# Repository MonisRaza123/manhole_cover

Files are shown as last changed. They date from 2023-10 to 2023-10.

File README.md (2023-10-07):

# MCMS (Manhole Cover Monitoring System)

## Problem Statement
Theft of manhole covers is a severe problem faced by our nation that has been left unaddressed for a long time.The repercussions of this thievery not only amount to material losses but also lead to loss of lives. This project proposes a solution to this problem by building a manhole cover monitoring system. Given that a sensor placed inside the manhole will not have reliable connection to the internet, we can directly send the sensor details using internet. This system will give the real-time status of the covers using a LoRa-based gateway to send the data to a cloud server keeping the authorities informed.

## Introduction and Motivation
Theft of manhole covers leads to accidents and deaths. At
first, this might seem like a very unlikely problem, but in
2004 Calcutta witnessed the theft of more than 10000
manhole covers over a period of two months. Thieves
steal these covers to sell them as scrap iron, the profit
made out of these acts is not much but the loss incurred
by society is much greater.
This type of theft is performed at locations experiencing
less traffic and spots which are not monitored with CCTV
cameras. These uncovered holes pose serious danger to
vehicles, especially two-wheelers which end in fatal crashes.
The pedestrians might be able to spot a big hole in daylight
but at night in darkness the chances of any mishappening
increase manifold.
Thus it becomes imperative to come up with a solution
to curb these acts of petty thievery leading to unfortunate
fatalities.

## Proposed Solution
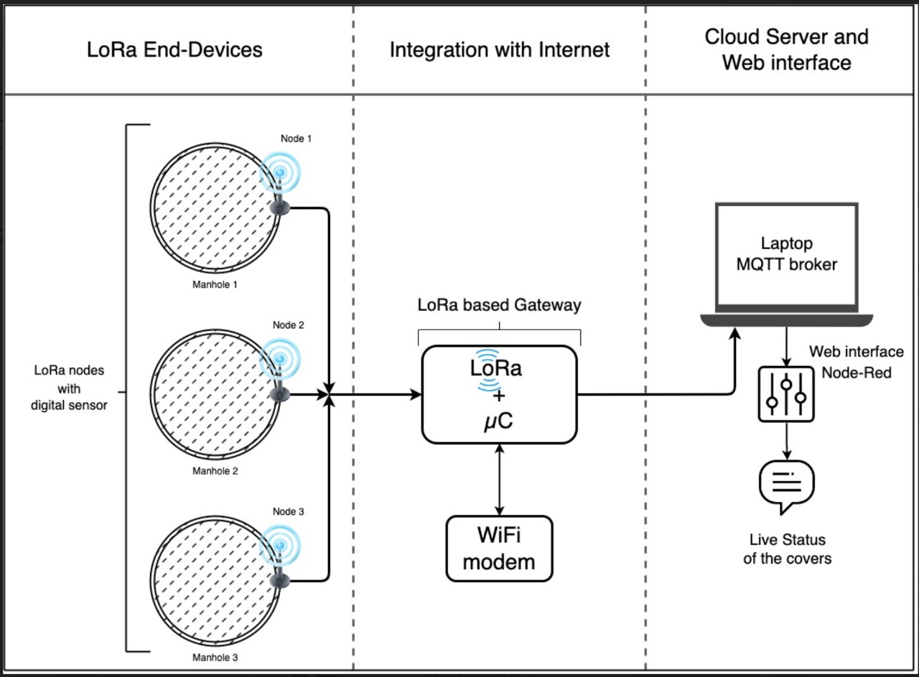
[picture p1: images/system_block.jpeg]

The suggested model is represented in three sections:

1. **LoRa end-devices:** The end devices are composed of sensors capable of
monitoring the status of the cover on the manhole.
The microcontroller reading this sensor is integrated
with a LoRa transmitter.
1. **Integrating internet connectivity:** Signals from the nodes of a given region would be
received by a common LoRa-based gateway connected
to an internet access point.
1. **Cloud server and web interface:** Using the connectivity provided by the gateway, the
data is uploaded to a cloud-based server and displayed
on a web interface or sent to the municipal authorities.

## Block Diagram Representation
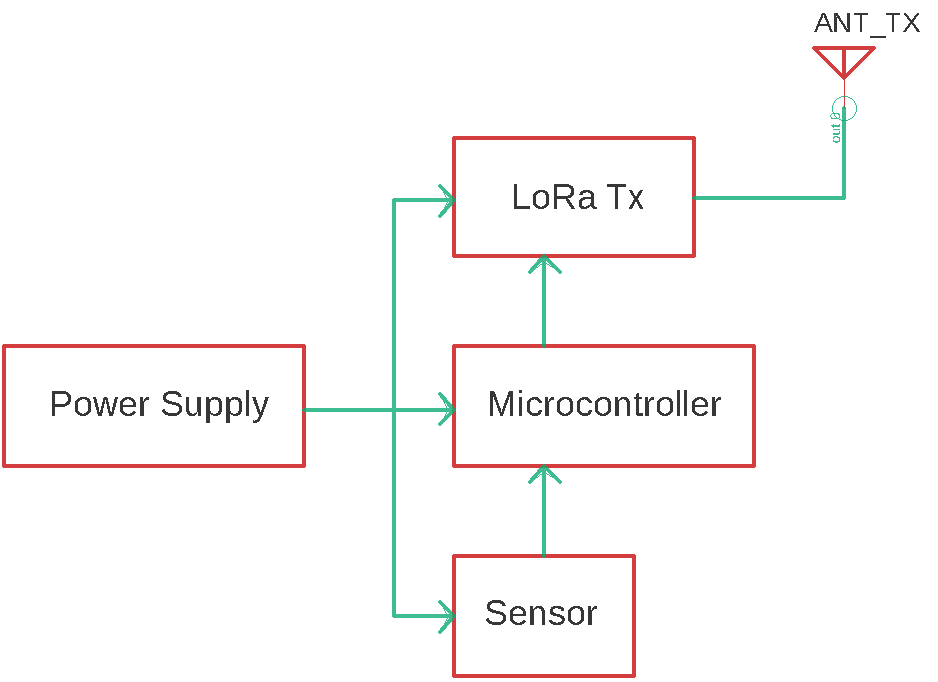
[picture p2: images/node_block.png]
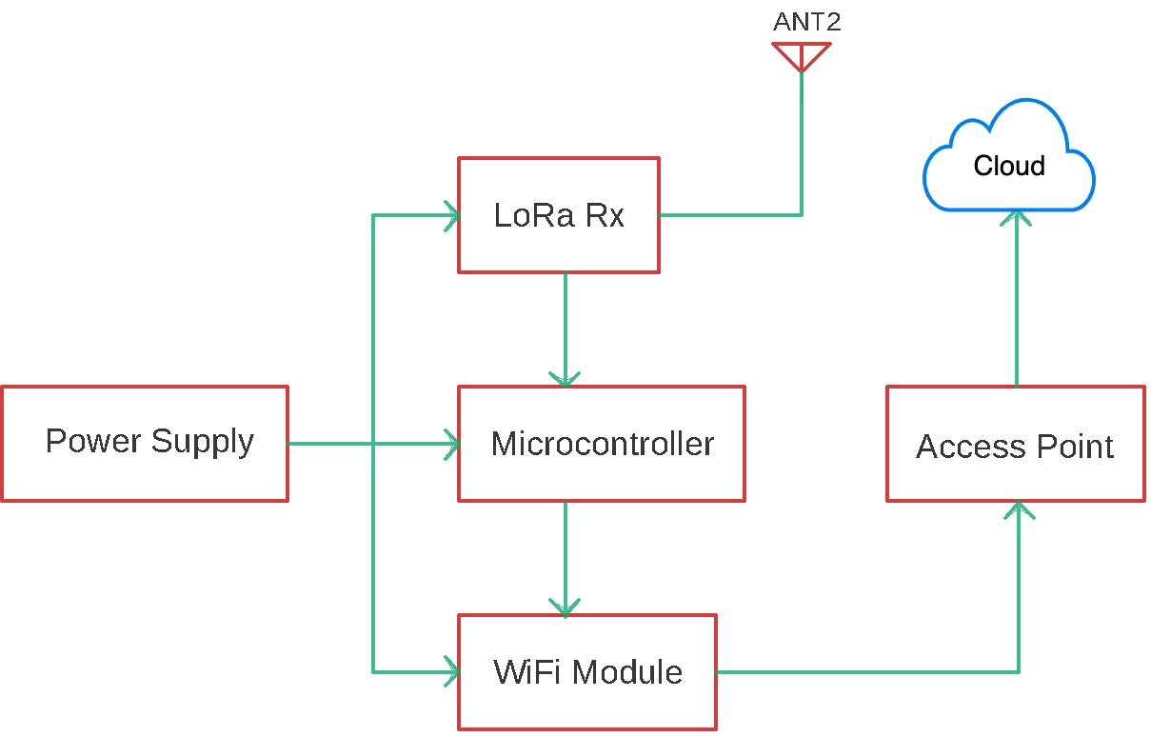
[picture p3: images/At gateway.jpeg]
|||
|:--:|:--:|
|*Manhole(End Node)*|*Gateway*|

## Six Box Model
The following is the list of requirements for the proposed solution as per the 'Six box Model' for embedded systems:
- Input sensor to detect the status of the manhole cover.
- Wireless technology for transferring sensor information.
- Cloud server acting as the host and storage for the required data.
- Microcontroller to process and control the node and gateway.
- Power supply for the node and gateway.
- Output devices to access the monitoring of the manhole covers.

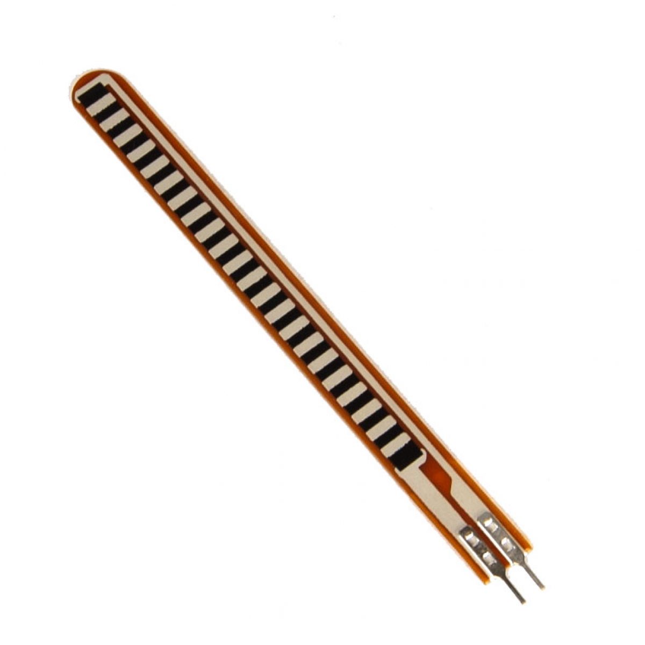
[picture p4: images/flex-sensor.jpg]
|1. INPUT- Flex sensor is used as the input sensor to detect the status of the manhole cover by bending at different angles. The resistance of the sensor changes with change in bending angle thereby facilitating the detection of the presence/absence of the cover.||
|:--|--:|
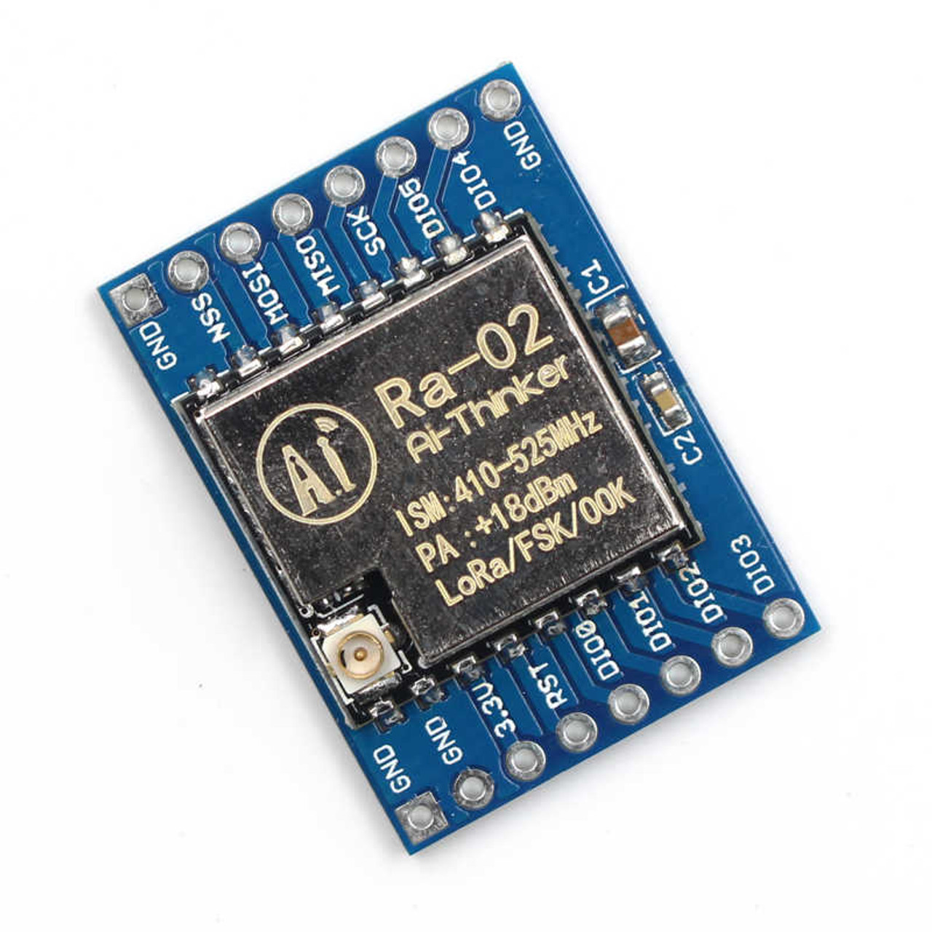
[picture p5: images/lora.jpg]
|2. COMMUNICAITON- LoRa communication is used as the preferred communication technology between the sensor node and the gateway because: i) Internet connectivity is not a viable option for the application. ii) LoRa is ideal for low bandwidth battery operated systems as it consumes minimal power ||
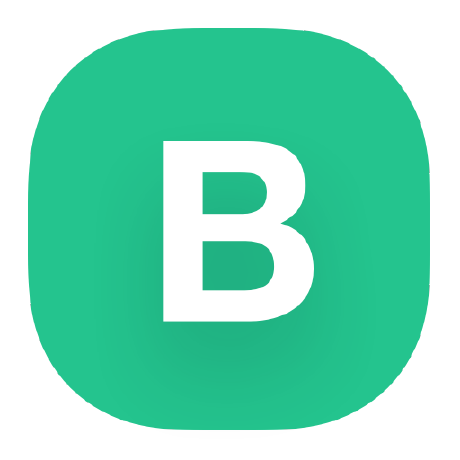
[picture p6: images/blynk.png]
|3. HOST & STORAGE- Blynk IOT serves as the cloud service provider. It stores and hosts the cover status of multiple node devices centrally which can then be fetched remotely from anyplace and anytime.||
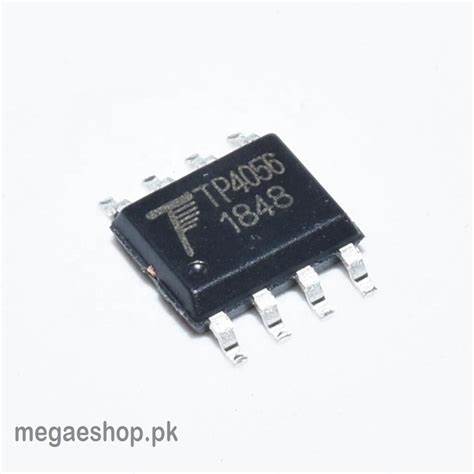
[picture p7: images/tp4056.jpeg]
|4. POWER SUPPLY- The end nodes are powered by a battery and as such need to be charged periodically.The TP4056 is a complete constant-current/constant-voltage linear charger for single-cell lithium-ion batteries. Its SOP package and low external component count make the TP4056 ideally suited for portable applications. The gateway device is powered by a 5V DC adapter||

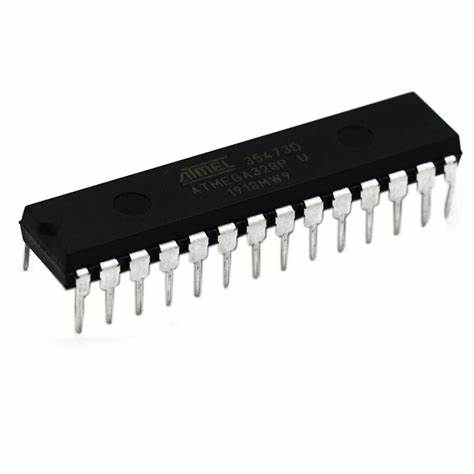
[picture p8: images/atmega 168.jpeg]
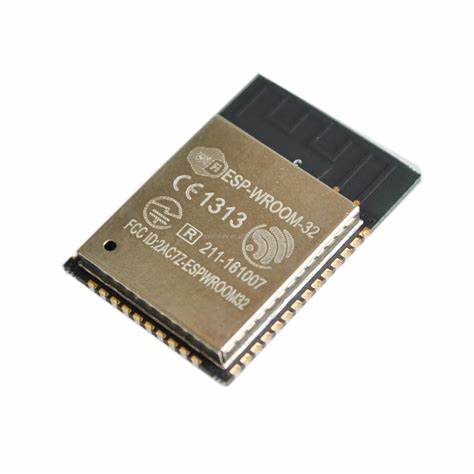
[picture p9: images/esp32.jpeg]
|<span style="font-weight:normal">5. MICROCONTROLLERS- ATMEGA168 is the microcontroller of choice for the end node as it consumes very less power and has just the right amount of features to cater to the needs of the end device. ESP32 is used as the microcontroller at the gateway as it requires internet connectivity serving as the internet access point for multiple end nodes. The communication between the end-nodes and gateway is done using Lora transceivers as stated earlier</span>|||
|:--|--|--:|

## Circuit Design

### Schematics
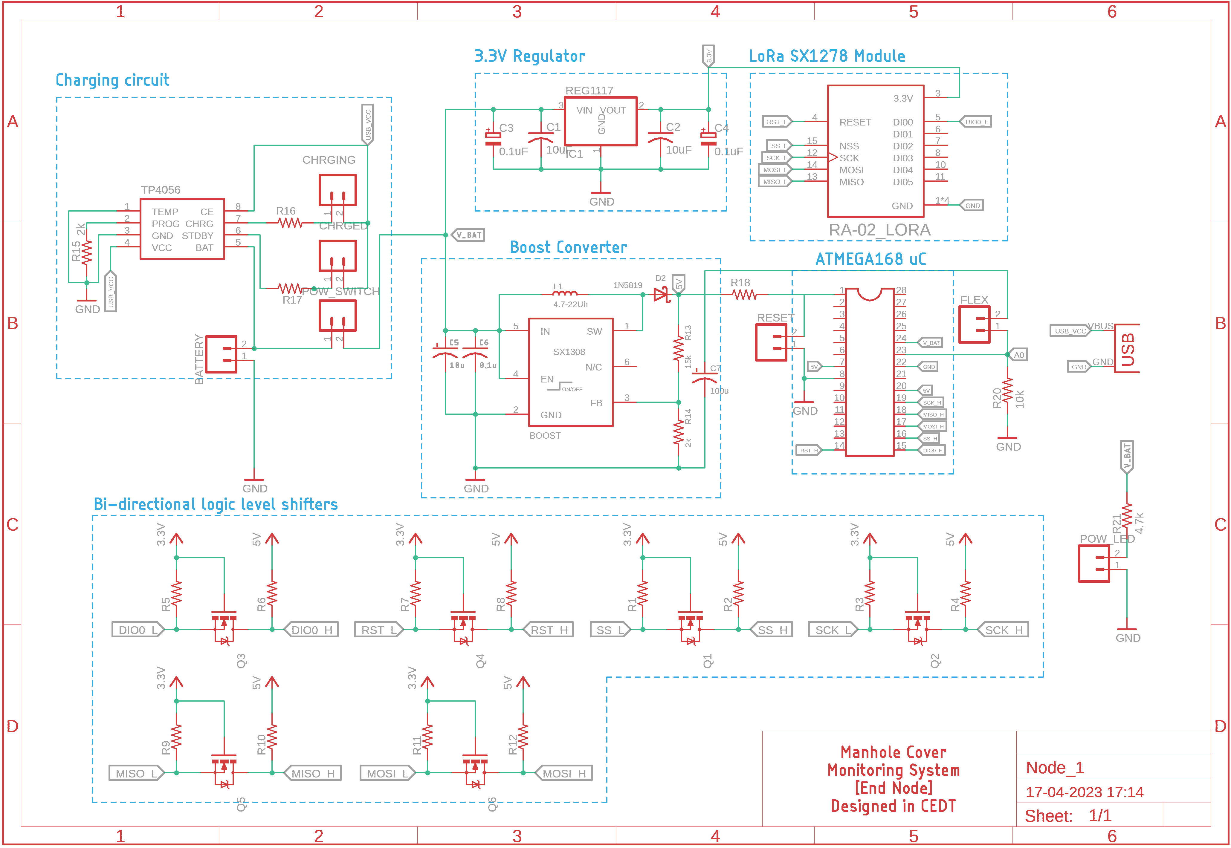
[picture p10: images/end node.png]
||
|:--:|
|*Schematic for End Node*|

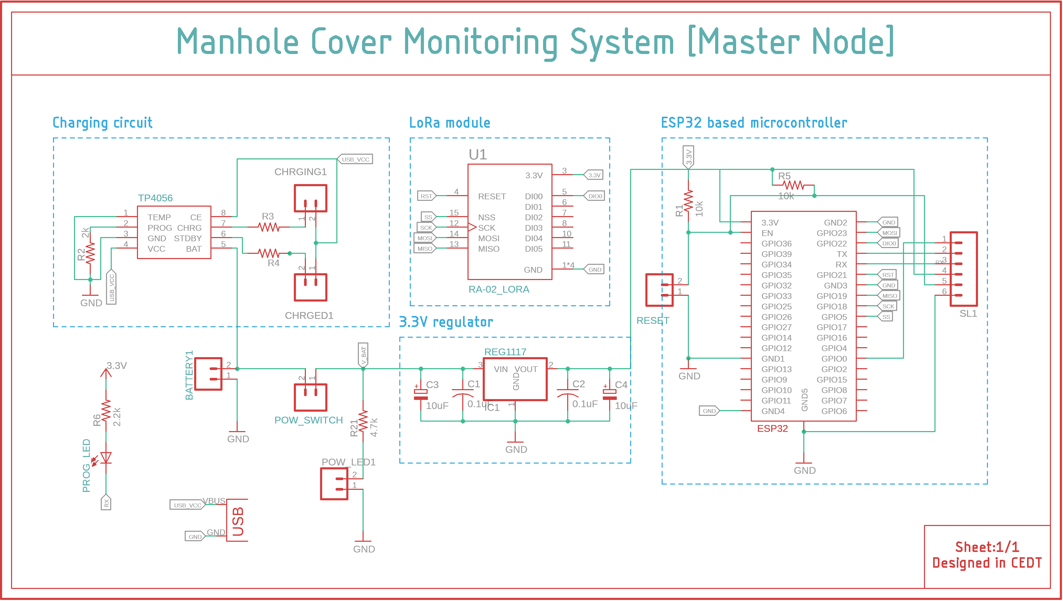
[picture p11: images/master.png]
||
|:--:|
|*Schematic for Master Node/Gateway*|

### Board Layouts
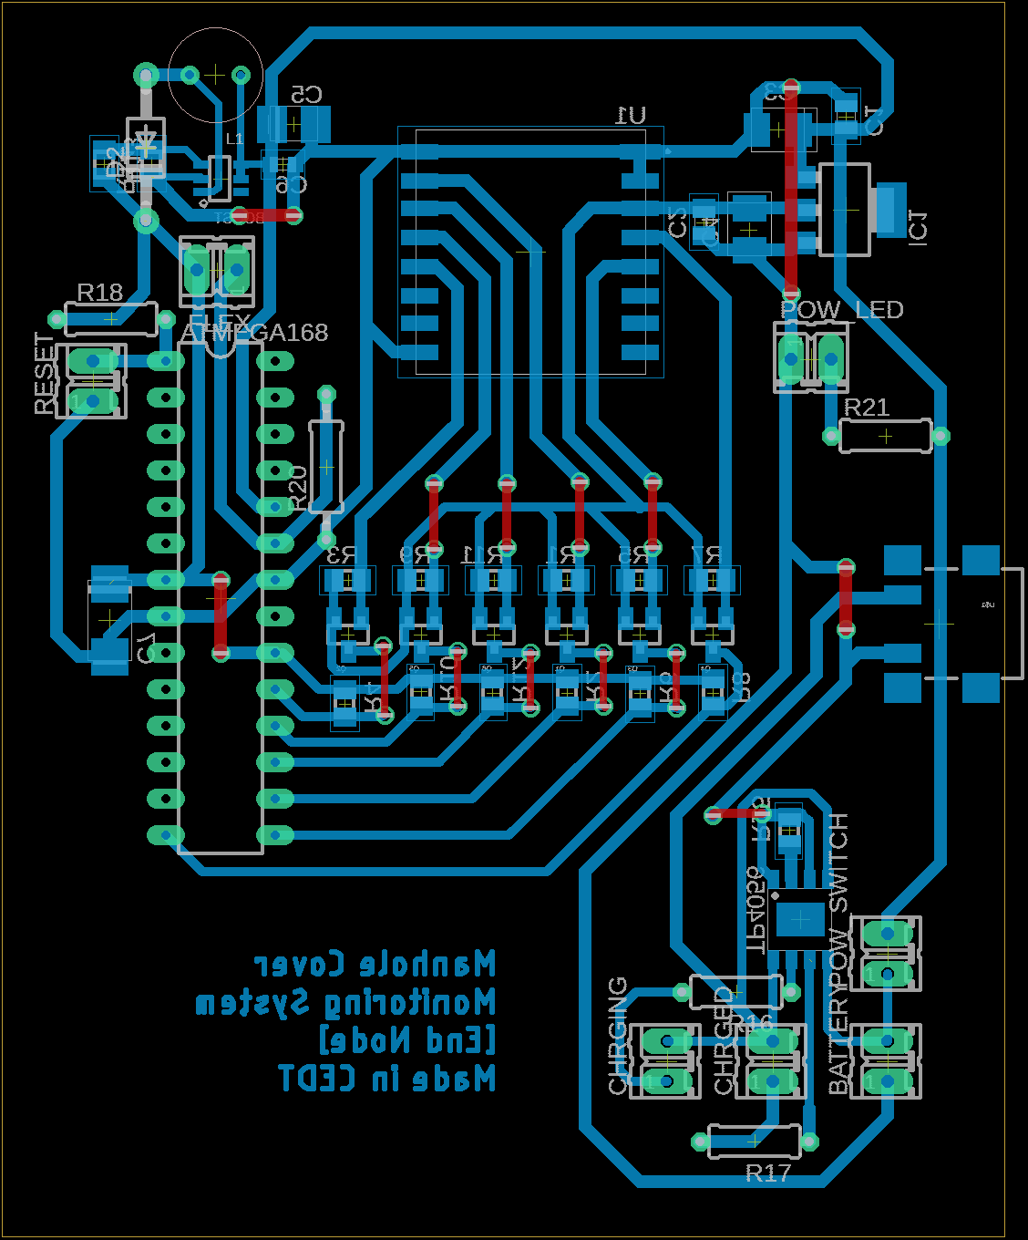
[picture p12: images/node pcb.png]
||
|:--:|
|*END NODE board layout*|

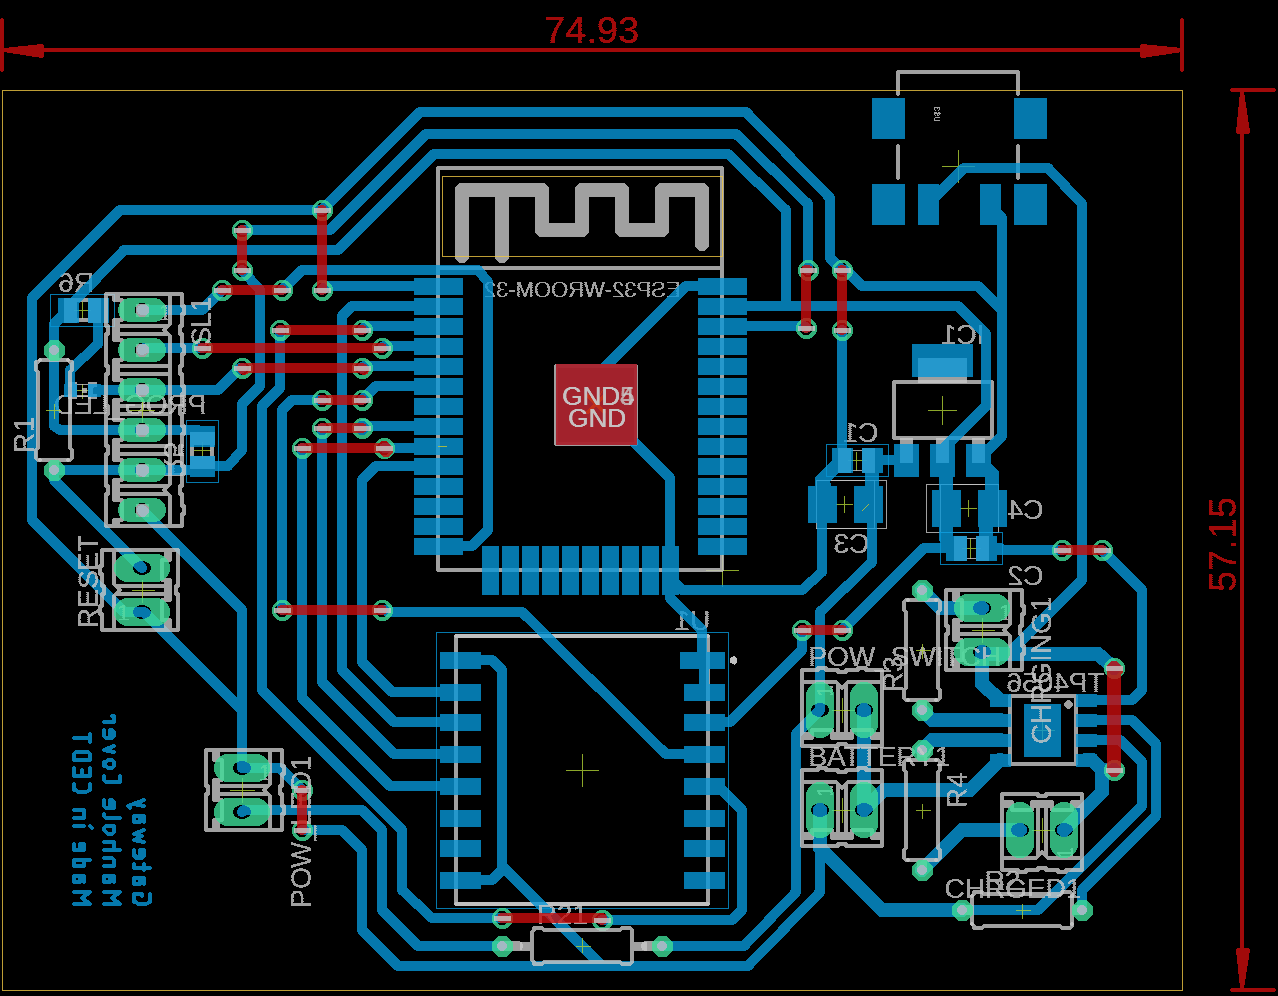
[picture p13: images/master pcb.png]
||
|:--:|
|*MASTER NODE board layout*|

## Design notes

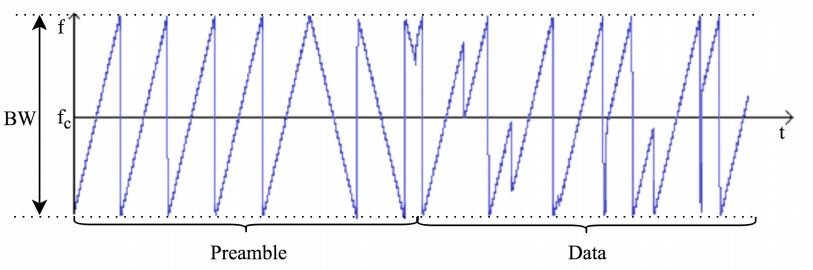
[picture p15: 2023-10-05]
images/lora freq.png

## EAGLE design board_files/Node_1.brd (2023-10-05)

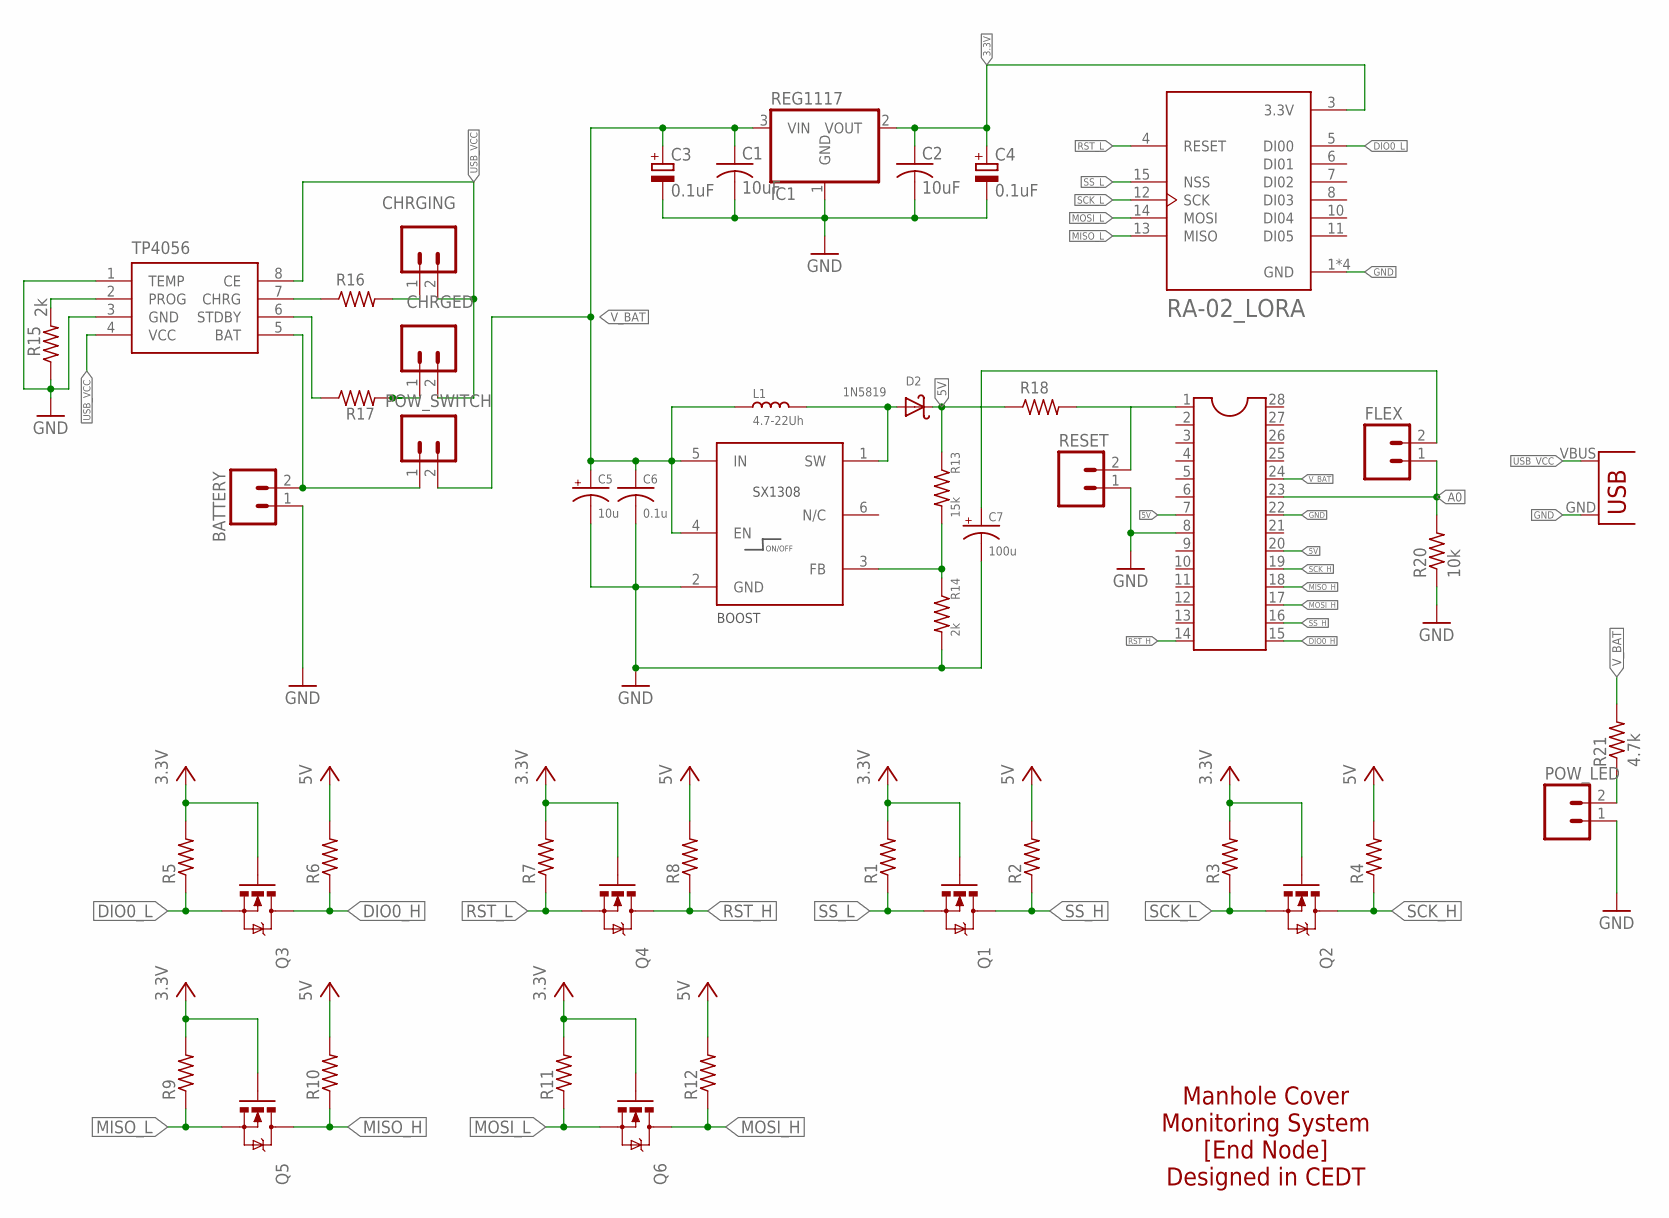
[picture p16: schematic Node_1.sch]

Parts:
ATMEGA168: DIL28-3
BATTERY: M02; 02P
BOOST: SX1308; SOT-23-6
C1, C2: 10uF; C0805
C3, C4: 0.1uF; CAPMP3528X210N
C5: 10u; B/3528-21R
C6: 0.1u; C0603
C7: 100u; C/6032-28R
CHRGED: M02; 02P
CHRGING: M02; 02P
D2: 1N5819; DO41-10
FLEX: M02; 02P
IC1: REG1117; SOT223
L1: 4.7-22Uh; INDUCTOR_INT2-3.5-D6.5XH8.0MM
POW_LED: M02; 02P
POW_SWITCH: M02; 02P
Q1, Q2, Q3, Q4, Q5, Q6: MOSFET-NCHANNELBSS138; SOT23
R1, R2, R3, R4, R5, R6, R7, R8, R9, R10, R11, R12: RESISTOR0805; R0805
R13: 15k; M0805
R14: 2k; M0805
R15: 2k; R0805
R16, R17: 470; 0207/7
R18: 10k; 0207/7
R20: 10k; 0207/10
R21: 4.7k; 0207/7
RESET: M02; 02P
TP4056: TP4056; SOP-8
U1: RA-02_LORA; MODULE_RA-02_LORA
U$1: USB(POWER)

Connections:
3.3V: C2.1, C4.1 (+), IC1.2 (VOUT), Q1.1 (G), Q2.1 (G), Q3.1 (G), Q4.1 (G), Q5.1 (G), Q6.1 (G), R1.2, R3.2, R5.2, R7.2, R9.2, R11.2, U1.3 (3.3V)
5V: ATMEGA168.7, ATMEGA168.20, C7.+, D2.C, FLEX.2, R2.2, R4.2, R6.2, R8.2, R10.2, R12.2, R13.1, R18.1
A0: ATMEGA168.23, FLEX.1, R20.2
BAT: BATTERY.2, POW_SWITCH.1, TP4056.5 (BAT)
DIO0_H: ATMEGA168.15, Q3.3 (D), R6.1
DIO0_L: Q3.2 (S), R5.1, U1.5 (DI00)
GND: ATMEGA168.8, ATMEGA168.22, BATTERY.1, BOOST.2 (GND), C1.2, C2.2, C3.2 (-), C4.2 (-), C5.-, C6.2, C7.-, IC1.1 (GND), POW_LED.1, R14.2, R15.1, R20.1, RESET.1, TP4056.1 (TEMP), TP4056.3 (GND), U1.1 (GND), U1.2 (GND), U1.9 (GND), U1.16 (GND), U$1.GND
MISO_H: ATMEGA168.18, Q5.3 (D), R10.1
MISO_L: Q5.2 (S), R9.1, U1.13 (MISO)
MOSI_H: ATMEGA168.17, Q6.3 (D), R12.1
MOSI_L: Q6.2 (S), R11.1, U1.14 (MOSI)
unnamed: BOOST.1 (SW), D2.A, L1.2
unnamed: R15.2, TP4056.2 (PROG)
unnamed: R16.1, TP4056.7 (CHRG)
unnamed: POW_LED.2, R21.1
unnamed: BOOST.3 (FB), R13.2, R14.1
unnamed: R17.1, TP4056.6 (STDBY)
unnamed: CHRGING.1, R16.2
unnamed: ATMEGA168.1, R18.2, RESET.2
unnamed: CHRGED.1, R17.2
RST_H: ATMEGA168.14, Q4.3 (D), R8.1
RST_L: Q4.2 (S), R7.1, U1.4 (RESET)
SCK_H: ATMEGA168.19, Q2.3 (D), R4.1
SCK_L: Q2.2 (S), R3.1, U1.12 (SCK)
SS_H: ATMEGA168.16, Q1.3 (D), R2.1
SS_L: Q1.2 (S), R1.1, U1.15 (NSS)
USB_VCC: CHRGED.2, CHRGING.2, TP4056.4 (VCC), TP4056.8 (CE), U$1.VBUS (VCC)
V_BAT: ATMEGA168.24, BOOST.4 (EN), BOOST.5 (IN), C1.1, C3.1 (+), C5.+, C6.1, IC1.3 (VIN), L1.1, POW_SWITCH.2, R21.2

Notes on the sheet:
Manhole Cover Monitoring System [End Node] Designed in CEDT

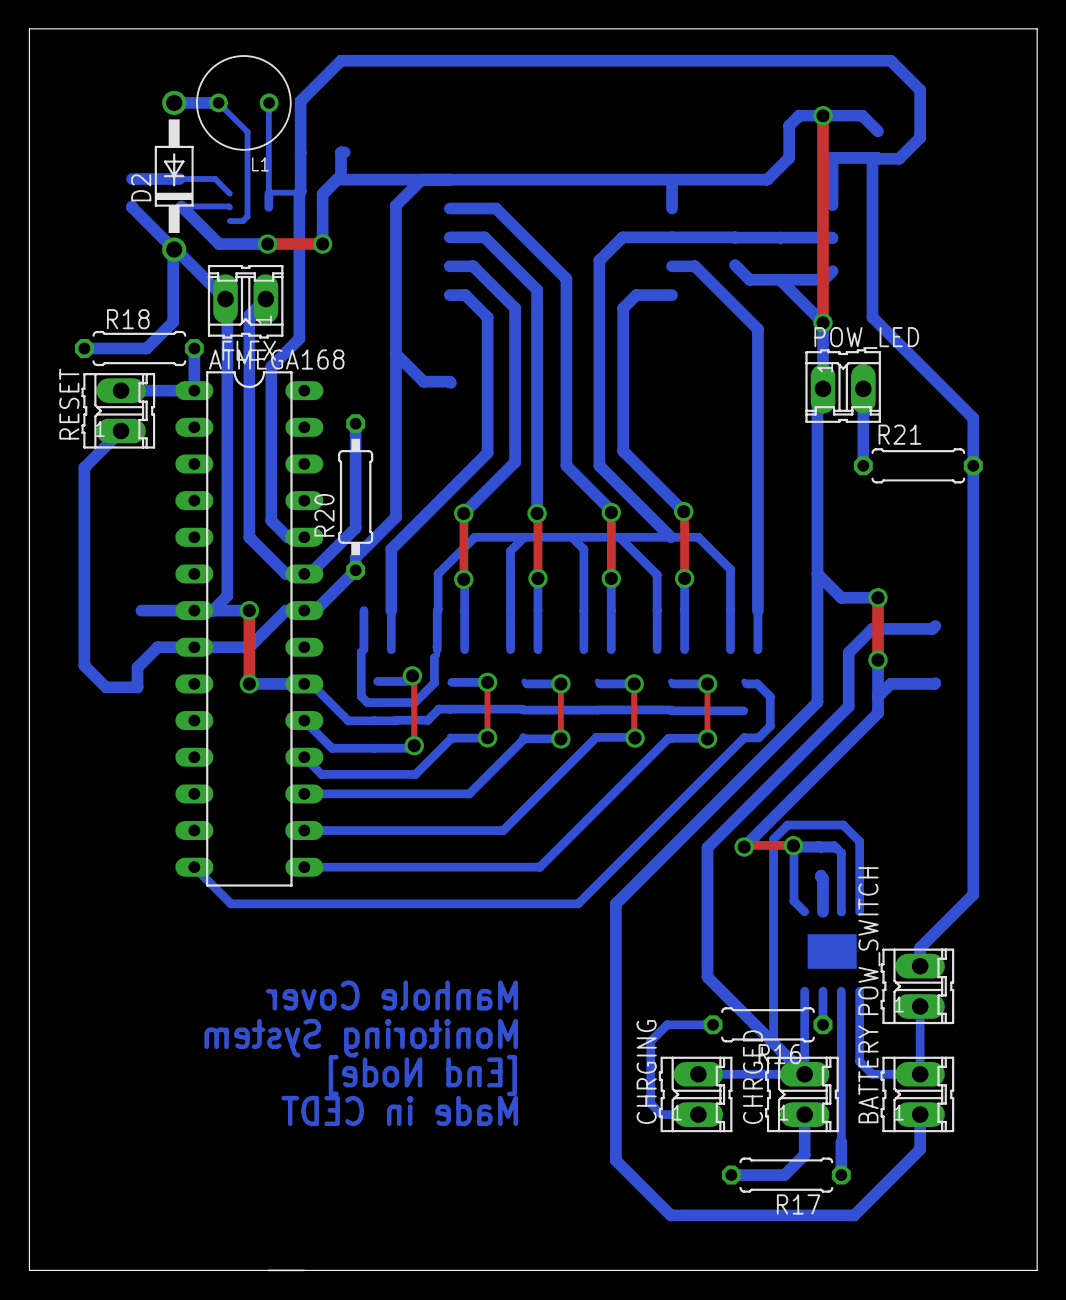
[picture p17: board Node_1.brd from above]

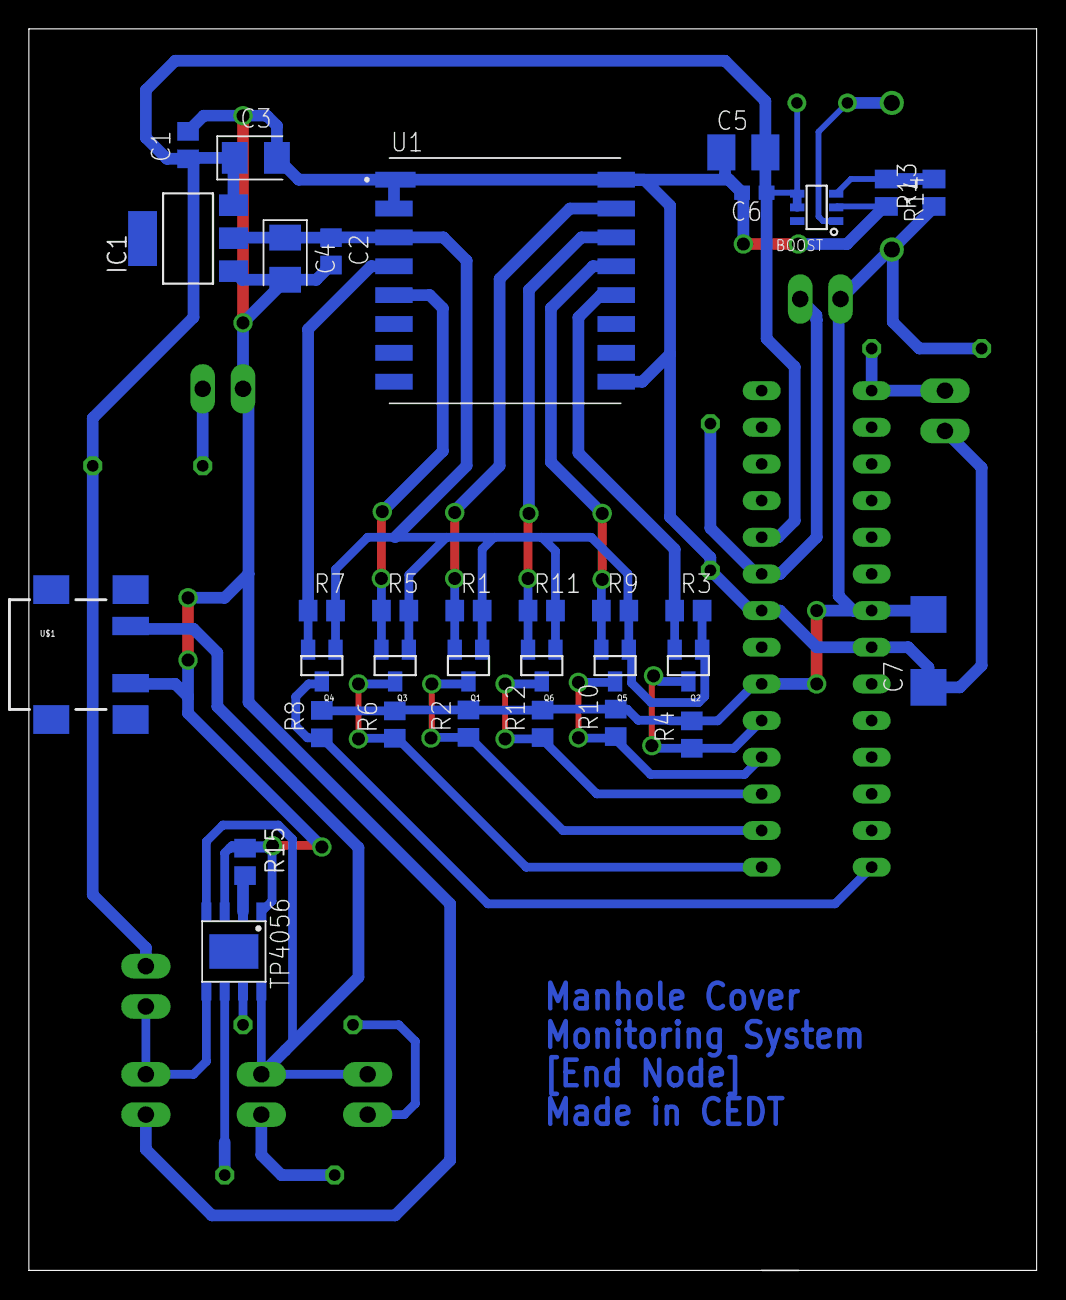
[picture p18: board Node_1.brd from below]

Board: 2 copper layers, 69.8 x 86.0 mm, 48 parts (33 on the bottom side), 28 nets.

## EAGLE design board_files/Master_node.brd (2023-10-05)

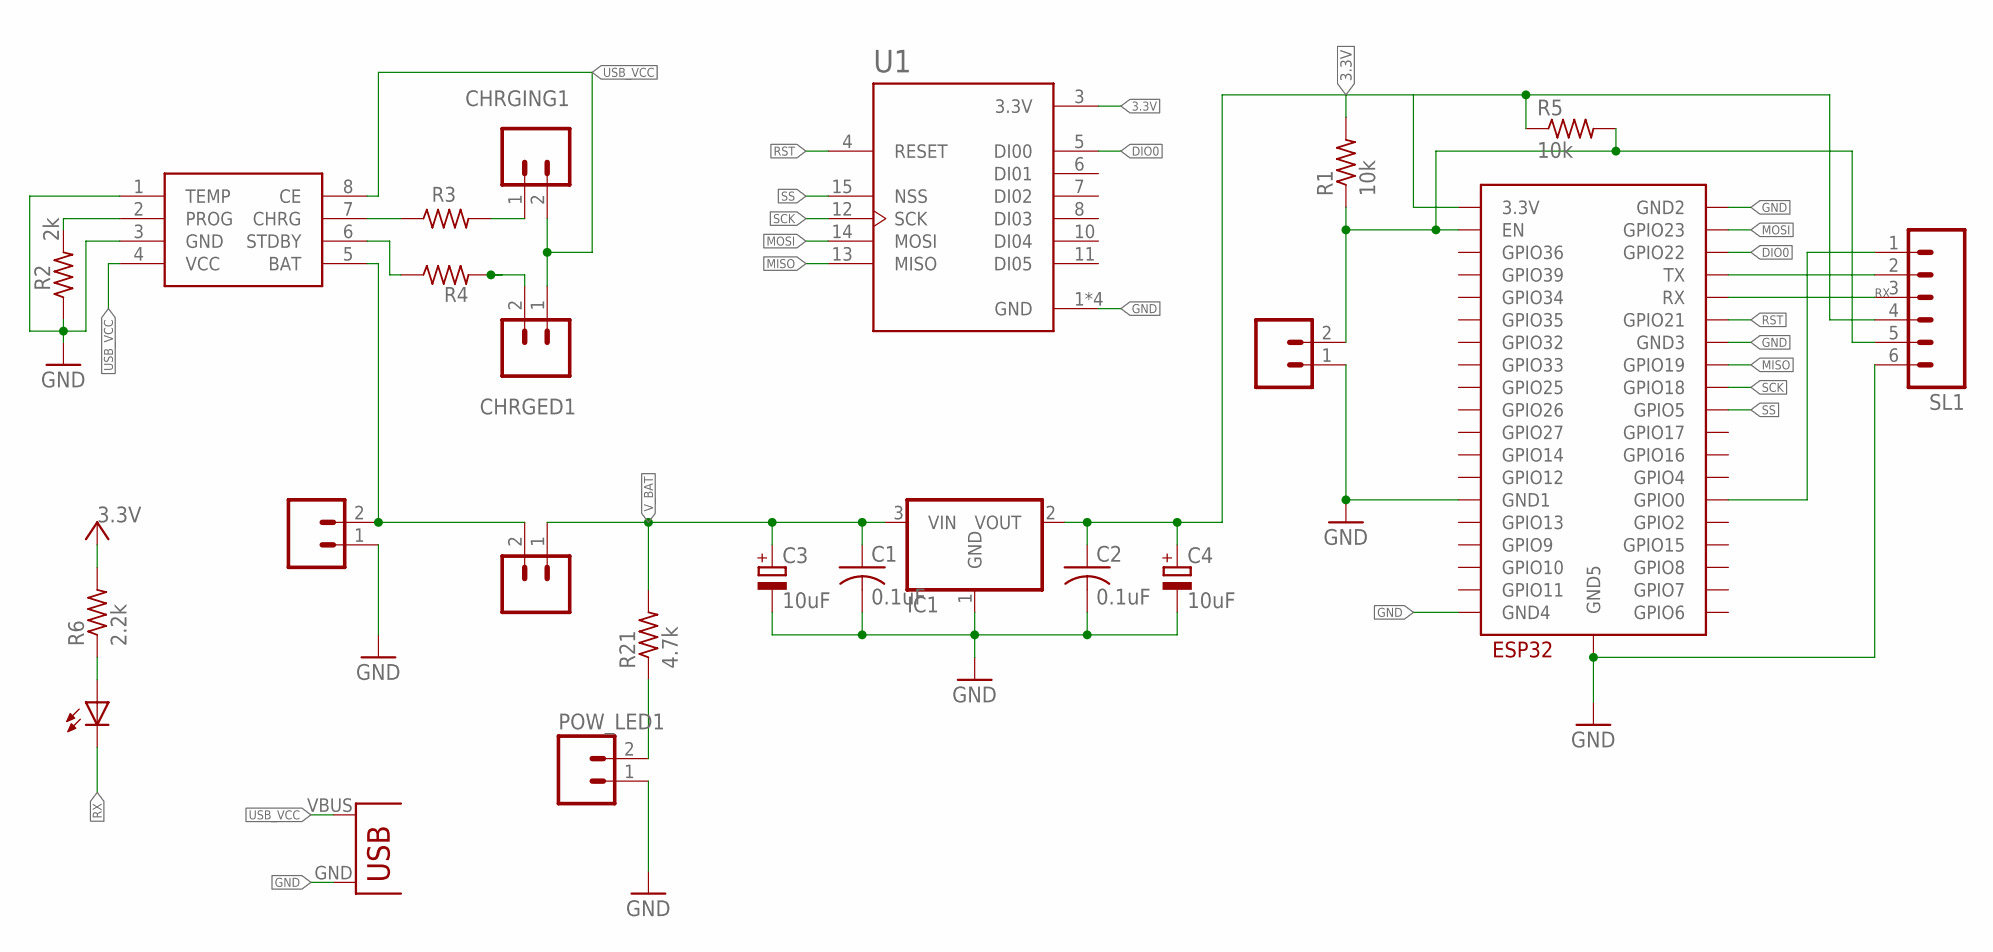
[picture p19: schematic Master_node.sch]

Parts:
BATTERY1: M02; 02P
C1, C2: 0.1uF; C0805
C3, C4: 10uF; CAPMP3528X210N
CHRGED1: M02; 02P
CHRGING1: M02; 02P
IC1: REG1117; SOT223
POW_LED1: M02; 02P
POW_SWITCH: M02; 02P
PROG_LED: LED0603; CHIPLED_0603
R1: 10k; 0207/7
R2: 2k; 0207/7
R3, R4: 470; 0207/7
R5: 10k; R0805
R6: 2.2k; R0805
R21: 4.7k; 0207/10
RESET: M02; 02P
SL1: M06; 06P
TP4056: TP4056; SOP-8
U1: RA-02_LORA; MODULE_RA-02_LORA
U$1: ESP32-WROOM
U$3: USB(POWER)

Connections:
3.3V: C2.1, C4.1 (+), IC1.2 (VOUT), R1.2, R5.1, R6.2, SL1.4, U1.3 (3.3V), U$1.3V3 (3.3V)
BAT: BATTERY1.2, POW_SWITCH.2, TP4056.5 (BAT)
DIO0: U1.5 (DI00), U$1.IO22 (GPIO22)
GND: BATTERY1.1, C1.2, C2.2, C3.2 (-), C4.2 (-), IC1.1 (GND), POW_LED1.1, R2.1, RESET.1, SL1.6, TP4056.1 (TEMP), TP4056.3 (GND), U1.1 (GND), U1.2 (GND), U1.9 (GND), U1.16 (GND), U$1.GND1, U$1.GND2, U$1.GND3, U$1.GND4, U$1.GND5, U$3.GND
MISO: U1.13 (MISO), U$1.IO19 (GPIO19)
MOSI: U1.14 (MOSI), U$1.IO23 (GPIO23)
unnamed: R1.1, R5.2, RESET.2, SL1.5, U$1.EN
unnamed: SL1.2, U$1.TX
unnamed: SL1.1, U$1.IO0 (GPIO0)
unnamed: R2.2, TP4056.2 (PROG)
unnamed: CHRGING1.1, R3.2
unnamed: PROG_LED.A, R6.1
unnamed: CHRGED1.2, R4.2
unnamed: R3.1, TP4056.7 (CHRG)
unnamed: R4.1, TP4056.6 (STDBY)
unnamed: POW_LED1.2, R21.1
RST: U1.4 (RESET), U$1.IO21 (GPIO21)
RX: PROG_LED.C, SL1.3, U$1.RX
SCK: U1.12 (SCK), U$1.IO18 (GPIO18)
SS: U1.15 (NSS), U$1.IO5 (GPIO5)
USB_VCC: CHRGED1.1, CHRGING1.2, TP4056.4 (VCC), TP4056.8 (CE), U$3.VBUS (VCC)
V_BAT: C1.1, C3.1 (+), IC1.3 (VIN), POW_SWITCH.1, R21.2

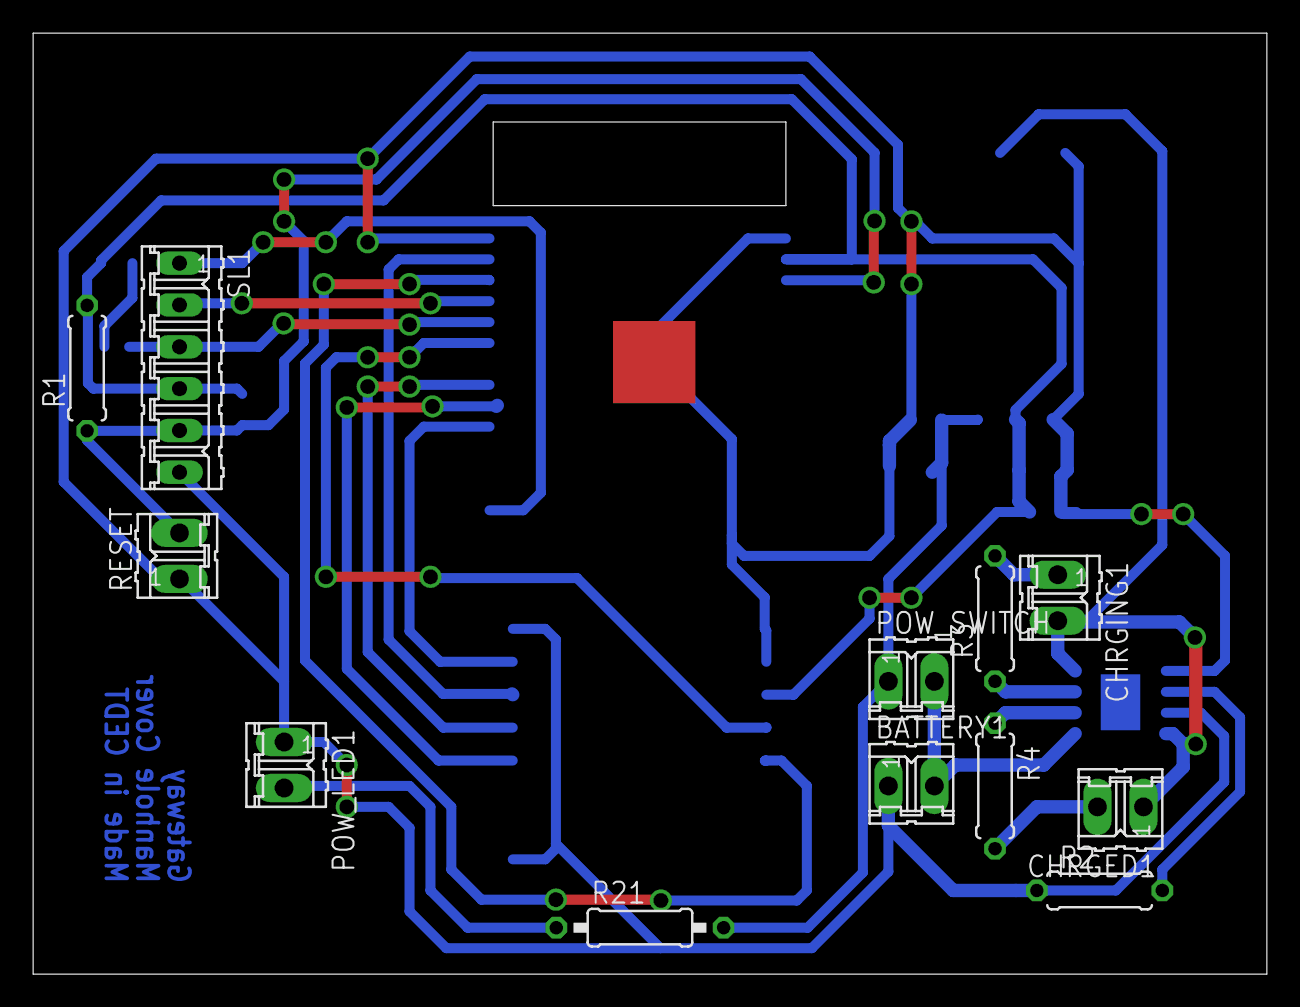
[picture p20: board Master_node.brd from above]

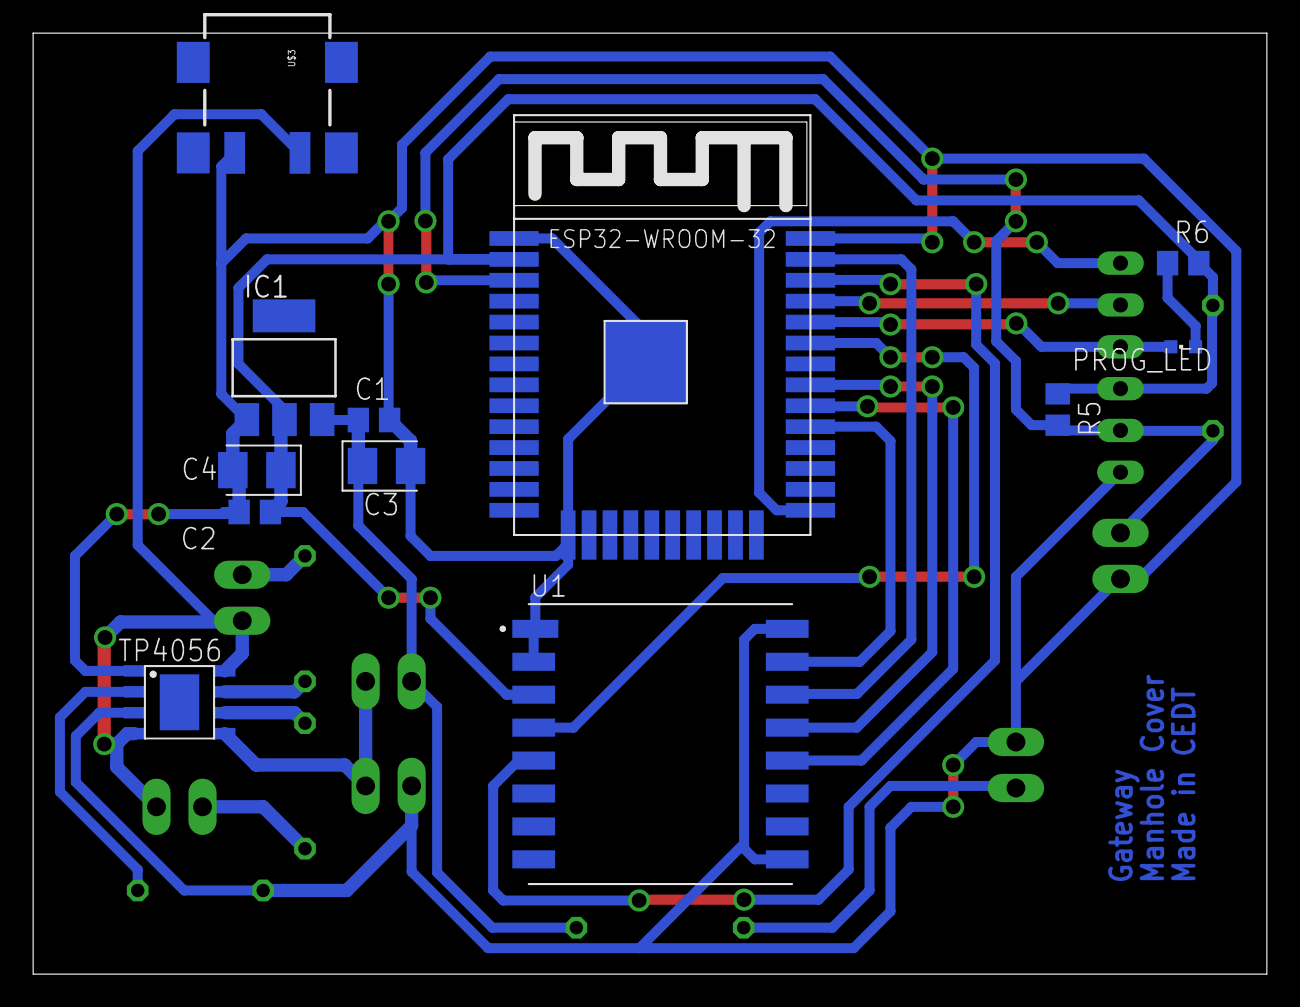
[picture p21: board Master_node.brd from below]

Board: 2 copper layers, 74.9 x 57.1 mm, 24 parts (12 on the bottom side), 22 nets.

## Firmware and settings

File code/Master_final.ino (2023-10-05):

//#include<Wire.h>
#include <SPI.h>
#include <LoRa.h>

#define ss 5
#define rst 21
#define dio0 22

byte MasterNode=0xCC;
byte Slave1=0xAA;
byte Slave2=0xBB;

String SenderNode = "";
String outgoing;              // outgoing message

byte msgCount = 0;            // count of outgoing messages

// Tracks the time since last event fired
unsigned long previousMillis = 0;
unsigned long int previoussecs = 0;
unsigned long int currentsecs = 0;
unsigned long currentMillis = 0;
int interval = 1 ; // updated every 1 second
int Secs = 0;

void setup() {
  // put your setup code here, to run once:
  Serial.begin(115200);

  while(!Serial);

  Serial.println("LoRa Master Node");

  LoRa.setPins(ss, rst, dio0);

  if (!LoRa.begin(433E6)) {
    Serial.println("Starting LoRa failed!");
    while (1);
  }

  

}

void loop() {
  // put your main code here, to run repeatedly:
  currentMillis=millis();
  currentsecs=currentMillis/1000;

   if ((unsigned long)(currentsecs - previoussecs) >= interval) {
    Secs = (Secs + 1)%11;
    
    if ( (Secs >= 1) && (Secs <= 5) )
    {
      Serial.println("sending 10");
      String message = "10";
      sendMessage(message, MasterNode, Slave1);
    }

    if ( (Secs >= 6 ) && (Secs <= 10))
    {
      Serial.println("sending 20");
      String message = "20";
      sendMessage(message, MasterNode, Slave2);
    }

    previoussecs = currentsecs;
  }

  
  // parse for a packet, and call onReceive with the result:
  onReceive(LoRa.parsePacket());

}

void sendMessage(String outgoing, byte MasterNode, byte otherNode) {
  LoRa.beginPacket();                   // start packet
  LoRa.write(otherNode);              // add destination address
  LoRa.write(MasterNode);             // add sender address
  LoRa.write(msgCount);                 // add message ID
  LoRa.write(outgoing.length());        // add payload length
  LoRa.print(outgoing);                 // add payload
  LoRa.endPacket();                     // finish packet and send it
  msgCount++;                           // increment message ID
}

void onReceive(int packetSize) {
  if (packetSize == 0) return;          // if there's no packet, return

  // read packet header bytes:
  int recipient = LoRa.read();          // recipient address
  byte sender = LoRa.read();            // sender address
  if ( sender == 0XAA )
    SenderNode = "Node1:";
  if ( sender == 0XBB )
    SenderNode = "Node2:";
  byte incomingMsgId = LoRa.read();     // incoming msg ID
  byte incomingLength = LoRa.read();    // incoming msg length

  String incoming = "";
  while (LoRa.available()) {
    incoming += (char)LoRa.read();
  }
  
  
  Serial.println("Received from: 0x" + String(sender, HEX));
  Serial.println("Sent to: 0x" + String(recipient, HEX));
  Serial.println("Message ID: " + String(incomingMsgId));
  Serial.println("Message length: " + String(incomingLength));
  Serial.println("Message: " + incoming);
  Serial.println("RSSI: " + String(LoRa.packetRssi()));
  Serial.println("Snr: " + String(LoRa.packetSnr()));
  Serial.println();
  
  
  if (incomingLength != incoming.length()) {   // check length for error
    Serial.println("error: message length does not match length");
    ;
    return;                             // skip rest of function
  }

  // if the recipient isn't this device,
  if (recipient != MasterNode) {
     Serial.println("This message is not for me.");
    ;
    return;                             // skip rest of function
  }

  // if message is for this device, print details:
   
}
  
